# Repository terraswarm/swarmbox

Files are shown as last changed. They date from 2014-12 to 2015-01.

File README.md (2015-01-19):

SwarmBox
========

Testbed for the swarm of things.

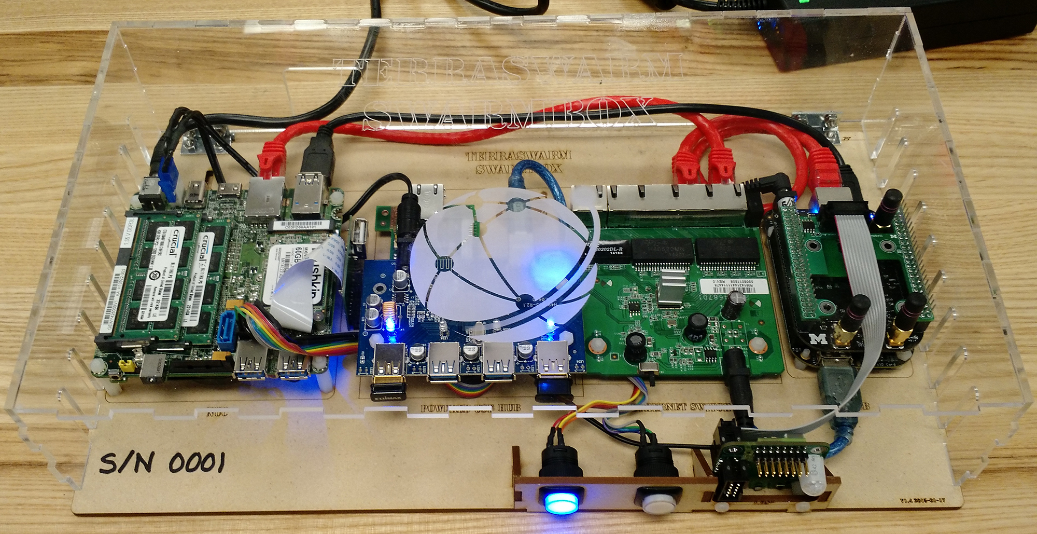
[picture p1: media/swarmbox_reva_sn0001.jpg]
Swarm Box RevA


Additional details documented in the [Terraswarm wiki](http://www.terraswarm.org/testbeds/wiki/Main/Hardware, "Terraswarm wiki, Hardware")

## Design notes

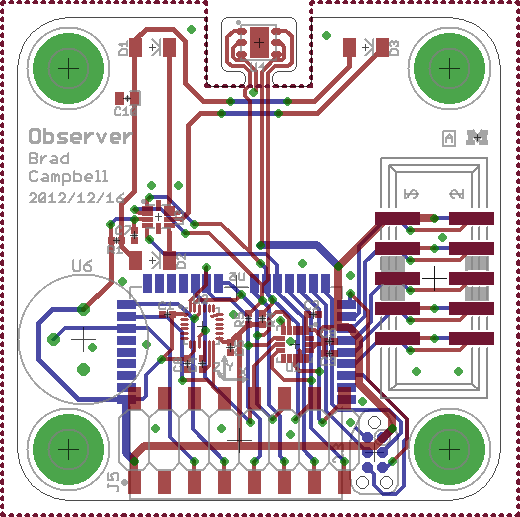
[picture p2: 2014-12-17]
hardware/observer/rev_a/observer_pcb.png

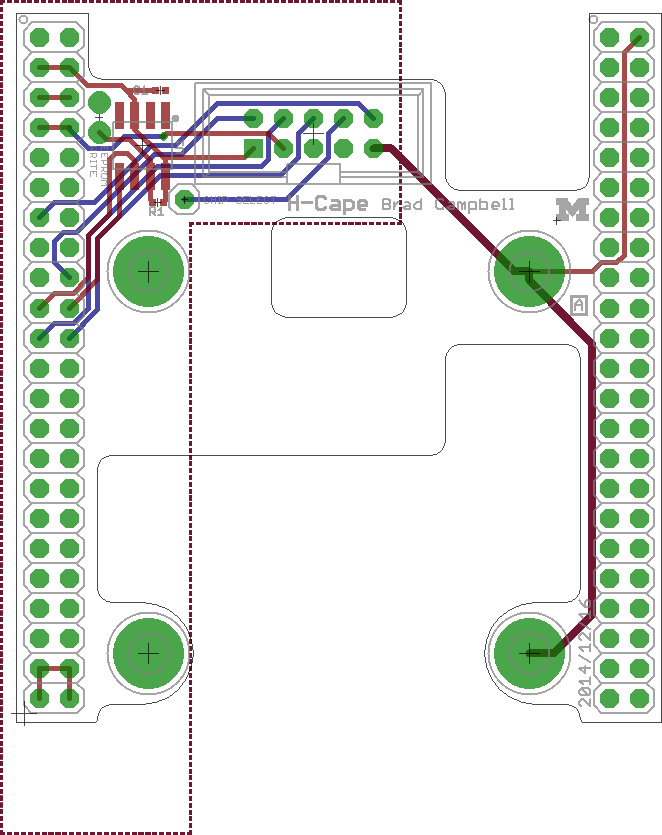
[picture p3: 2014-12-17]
hardware/ocape/rev_a/ocape_pcb.png

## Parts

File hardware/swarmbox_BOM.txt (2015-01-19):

Quantity   Component                 Model Number        Unit Cost        Link
--------   -----------------------   ----------------    ---------        ---------------------------------------------------------------
1          NUC (i5-4250U)            D54250WYB           $  352.99        http://www.newegg.com/Product/Product.aspx?Item=N82E16813121795
1          RAM (8GB)                 CT2CP51264BF160B    $   66.99        http://www.amazon.com/Crucial-4GBx2-DDR3-1600-CT2CP51264BF160B/dp/B005LDLVAO
1          SSD (80GB)                SSDMCEAW080A401     $   69.99        http://www.newegg.com/Product/Product.aspx?Item=N82E16820167196
1          PCIe Mini Adapter Cable   MPCIE-1XUSB-FLEX    $   27.60        http://www.amazon.com/PCI-E-Express-Riser-Speed-Cable/dp/B00JIV9AZS
1          i210 PCIe Card            E0X95AA             $   39.00        http://www.bhphotovideo.com/bnh/controller/home?sku=1024193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
1          Power Supply              FSP065-REB-R        $   25.99        http://www.newegg.com/Product/Product.aspx?Item=N82E16817104190

1          5 Port Ethernet Switch    GS105               $   30.19        http://www.amazon.com/NETGEAR-ProSafe-Gigabit-Ethernet-Desktop/dp/B0000BVYT3
1          Powered USB Hub           AH111               $   27.99        http://www.amazon.com/Anker¨-AH111-4-Port-Adapter-Chipset/dp/B005QWY3PU
1          BLE Dongle                MUA-BA3             $   11.99        http://www.amazon.com/Medialink-USB-Bluetooth-Adapter-Technology/dp/B004LNXO28
1          Wi-Fi Dongle              EW-7811Un           $    8.99        http://www.amazon.com/Edimax-EW-7811Un-150Mbps-Raspberry-Supports/dp/B003MTTJOY
1          USB Mini Cable            ?? (length?)
1          Ethernet Cat6 Cable       ?? (length?)
1          Ethernet Cat6 Cable       ?? (length?)

1 (??)     Power/Buttons Cable ??

1          Beaglebone Black Rev C    BB-BBLK-C           $   50.31        http://www.newark.com/element14/bbone-black-4g/beaglebone-black-rev-c-cortex/dp/52X5548

1          GAP Radio Board           GAP_C               $   75.00        https://github.com/lab11/beaglebone-cc2520/tree/master/hardware/eagle/bbb-cc2520/rev_c
1          H-Cape                    H-Cape_A            $   20.00
1          Observer                  Observer_C          $   80.00

1          Blue Push Button          1477                $    1.95        http://www.adafruit.com/products/1477
1          White Push Button         1479                $    1.95        http://www.adafruit.com/products/1479

??         3/4" (?) Standoffs
??         1/4" (?) Standoff
2          Hinges

1          Case                                                           https://github.com/terraswarm/swarmbox/tree/master/hardware/case

## OPTIONAL

1          PCIe Wi-Fi/BLE Card       INT-7260BR          $   23.99        http://www.superbiiz.com/detail.php?p=INT-7260BR
2          Wi-Fi Antenna             ??

## OLD, to be deleted

#5V 2A PSU for Beagle Bone        Received        $8        http://www.adafruit.com/products/276        2A needed for Wifi dongle+BBB
#uSD card        19x Received        $15.99        http://www.amazon.com/SanDisk-Memory-Adapter--SDSDQUAN-032G-G4A-Version/dp/B00M55C0NS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        BeagleBone Linux Image

usb 2.0 hub        20x received        $6.99        http://www.amazon.com/Sabrent-4-Port-Individual-Switches-HB-UMLS/dp/B00BWF5U0M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        For BBB wireless dongles etc.                                        http://www.amazon.com/Sabrent-4-Port-Individual-Switches-HB-UM43/dp/B00JX1ZS5O

standoffs        5 sets revceived        10.89        http://www.amazon.com/gp/product/B00LGB2N1Q/ref=ox_sc_act_image_2?ie=UTF8&psc=1&smid=A2W8GBH769XLCV        Holders for the NUC and Beaglebone
Z-Wave USB Stick        20x received        $39        http://www.amazon.com/Aeon-Labs-DSA02203-ZWUS-Z-Wave-Z-Stick/dp/B003MWQ30E        Aeon Labs
ethernet station cable x 2                $6                to go to local gig switch
Radio Cape                $75.00        Custom        Estimate (high)
Power Button                $1.95        http://www.adafruit.com/products/1477
Reset Buton/HDD Indicator                $1.95        http://www.adafruit.com/products/1479
WiFi Antennas x2                $9.90        http://www.mouser.com/Search/ProductDetail.aspx?R=47950-0001virtualkey53850000virtualkey538-47950-0001
Internal Power Header Conductors x2                $0.84        http://www.mouser.com/Search/ProductDetail.aspx?R=39-00-0039virtualkey53810000virtualkey538-39-00-0039
Internal Power Header                $0.61        http://www.mouser.com/Search/ProductDetail.aspx?R=39-02-7028virtualkey53850000virtualkey538-39-02-7028

Total Per Unit                $733.80

Accessories (couple per group)                Unit Cost
HDMI cable        8x received        $7        http://www.amazon.com/AmazonBasics-High-Speed-HDMI-Micro-Cable/dp/B0096LZ5QI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
usb a mini b cable        8x Received        $5.09        http://www.amazon.com/AmazonBasics-USB-Male-Mini-Cable/dp/B00E9IF9RI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
3M Velcro        1 set received        $75        http://www.amazon.com/CommandTM-Adhesive-Interlocking-Fasteners-ADHESIVE/dp/B0032K0EIS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        30 Pack
hdmi monitor                99        http://www.newegg.com/Product/Product.aspx?Item=N82E16824236115
usb keyboard        20x received        15.99        http://www.newegg.com/Product/Product.aspx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                with mouse and speakers
Beagle Bone Debug Console cable        10 x Revceived        19.95        http://www.amazon.com/3-3V-Debug-Cable-BeagleBone-Black/dp/B00FA7LD0Y
Esplora (sensors/actuator mix        CNMAT will bring loaners        49.99        http://www.radioshack.com/arduino-esplora-microcontroller-board/2760261.html#.VIKtJd6kZs8                light/temp/slider/rgb led/buttons/sound via usb
Optional hdmi to VGA                15.99        http://www.amazon.com/Cable-Matters-Active-Female-Adapter/dp/B00879EZJI/
Total Accessories                $186

For Workshop Experiments/Config
AVB switch        3 loaners received by Meyer Sound for workshop        295        http://www.bhphotovideo.com/bnh/controller/home?sku=1071378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        6-ports
24-bit qos switch        2x Received        169.99        http://www.amazon.com/TP-LINK-TL-SG2424-Snooping-Web-based-Management/dp/B009LEJL5Q                supports 12nucs and 12 bbb
PTZ camera with 2 way audio        3x received        63.99        http://www.amazon.com/Foscam-FI8910W-Network-Camera-Two-Way/dp/B006ZP8UOW        actuation and streaming source controllable with ZoneMinder for remote config guidance

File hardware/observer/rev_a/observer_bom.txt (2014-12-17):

# Bill of Materials
# Converted from observer_bom.xlsx
# Generated by bom_to_text.py

Qty  Value                         Device                        Package           Parts                   Description                                                 DIGIKEY
1    10nF                          CAPACITOR                     0402_CAP          C1                      0402 Capacitor                                              490-1312-1-ND
6    0.1uF                         CAPACITOR                     0402_CAP          C2, C3, C4, C5, C7, C8  0402 Capacitor                                              490-1318-1-ND
1    10uF                          CAPACITOR                     0402_CAP          C9                      0402 Capacitor                                              445-8919-1-ND
1    22uF                          CAP_POL0603                   CAP0603           C10                                                                                 511-1493-1-ND
3    SFH4056                       SFH4056                       SFH4056           D1, D2, D3              LED IR EMITTER 850NM                                        475-3042-1-ND
2    CON_HEADER_2X05-SMD+SHROUDED  CON_HEADER_2X05-SMD+SHROUDED  PINSHRD_SMT_2X05  J1, J2                  2x05 pin header                                             S9185-ND
1    PINHD-2X8/SMD                 PINHD-2X8/SMD                 2X8/SMD           J5                                                                                  609-3486-1-ND
1    30                            RESISTOR0402_RES              0402_RES          R1                      Resistor                                                    RHM30CECT-ND
2    10k                           RESISTOR0402_RES              0402_RES          R4, R5                  Resistor                                                    RHM10.0KCDCT-ND
1    LPS331AP                      LPS331AP                      HCLGA-16/3MM      U1                      IC PRESSURE SENSOR PIEZO 16HCLGA                            497-12927-1-ND
1    MPU-9250                      MPU-9250                      QFN-24/3MM        U2                      GYRO/ACCEL/COMPASS/9-AXIS                                   1428-1019-1-ND
1    SI1147                        SI1147                        QFN-10/2MM        U3                      SENSOR DGTL UV INDEX 10QFN                                  336-2624-1-ND
1    SI7021                        SI7021                        DFN-6/3MM         U4                      IC TEMP SENSOR RH 2% DFN                                    336-2542-1-ND
1    ATUM                          ATUM                          ATUM              U5                      Atum sensorboard prototyping module.                        
1    AMN41121                      AMN41121                      AMN2              U6                      Passive infrared human detection sensor with built-in amp.  255-2651-ND

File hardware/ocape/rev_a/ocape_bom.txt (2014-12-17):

# Bill of Materials
# Converted from ocape_bom.xlsx
# Generated by bom_to_text.py

Qty  Value                           Device                          Package                  Parts  Description                                                         DIGIKEY
1    100nF                           C-EUC0402                       C0402                    C1     CAPACITOR, European symbol                                          490-1318-1-ND
1    CON_HEADER_2X05-PTH+SHROUDED_A  CON_HEADER_2X05-PTH+SHROUDED_A  PINSHRD_PTH_2X05         J1     2x05 pin header                                                     ED1543-ND
1    JUMPER-PTH-2-NO                 JUMPER-PTH-2-NO                 PTH-JUMPER-2-NO_NO_SILK  J2                                                                         
1                                    PINHD-1X1                       1X01                     J3     PIN HEADER                                                          
1    BBB_HEADERS                     BBB_HEADERS                     BBB_HEADERS              P9/P8  Pin Header                                                          
1    10k 1%                          R-US_R0402                      R0402                    R1     RESISTOR, American symbol                                           RHM10.0KCDCT-ND
1    CAT24C256WI-GT3                 CAT24C256WI-GT3                 CAT24C256WI-GT3          U1     256kb Serial CMOS EEPROM, organized as 32,768 words of 8 bits each  CAT24C256WI-GT3OSCT-ND

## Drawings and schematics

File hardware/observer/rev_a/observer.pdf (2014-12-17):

Pressure Sensor | 9-DOF Accelerometer

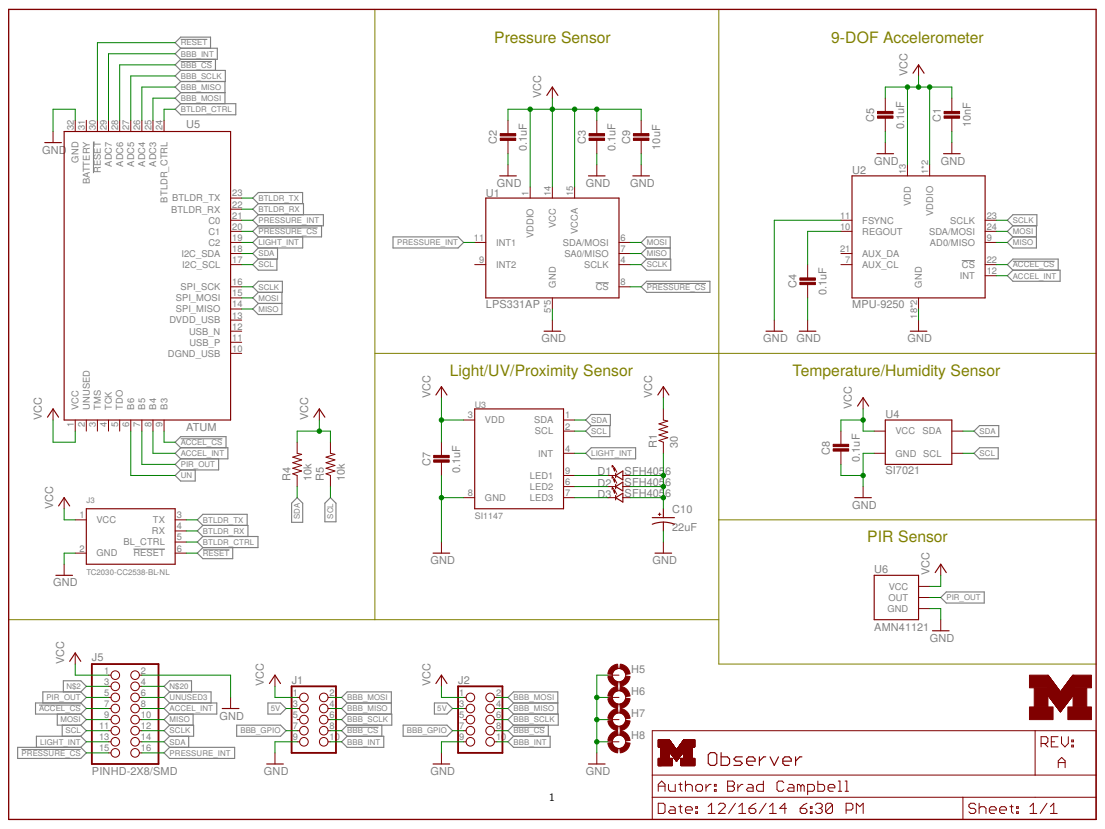
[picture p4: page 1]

Top and Bottom Layers 2 | 21 | 12

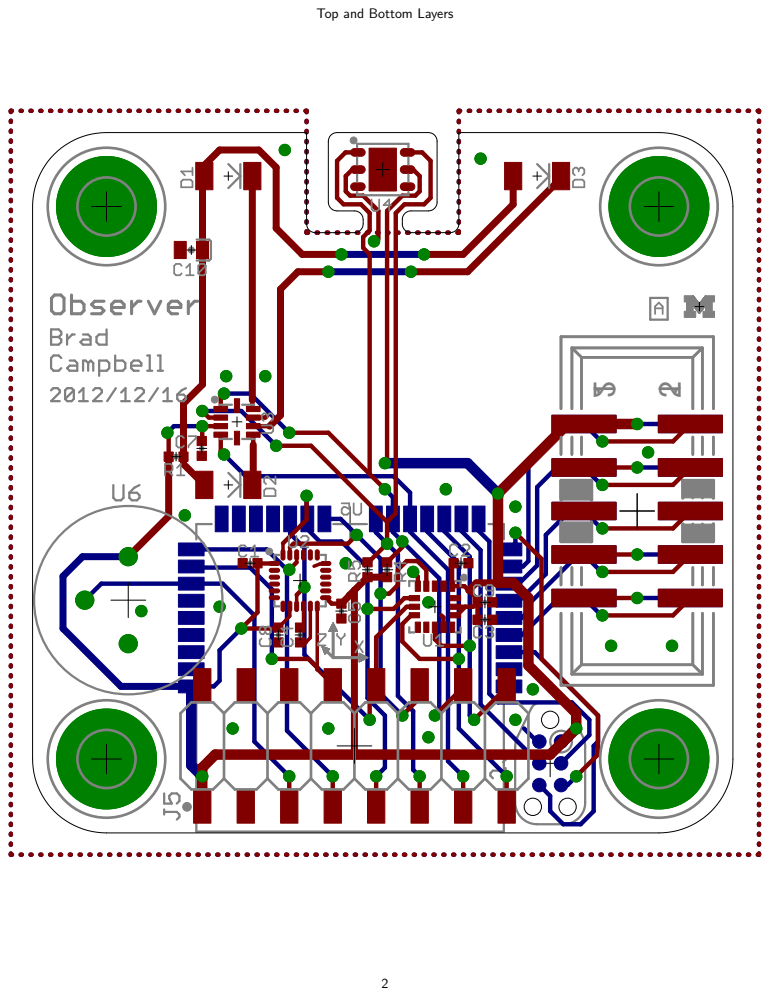
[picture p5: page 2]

Top Layer 3 | 1 | 2

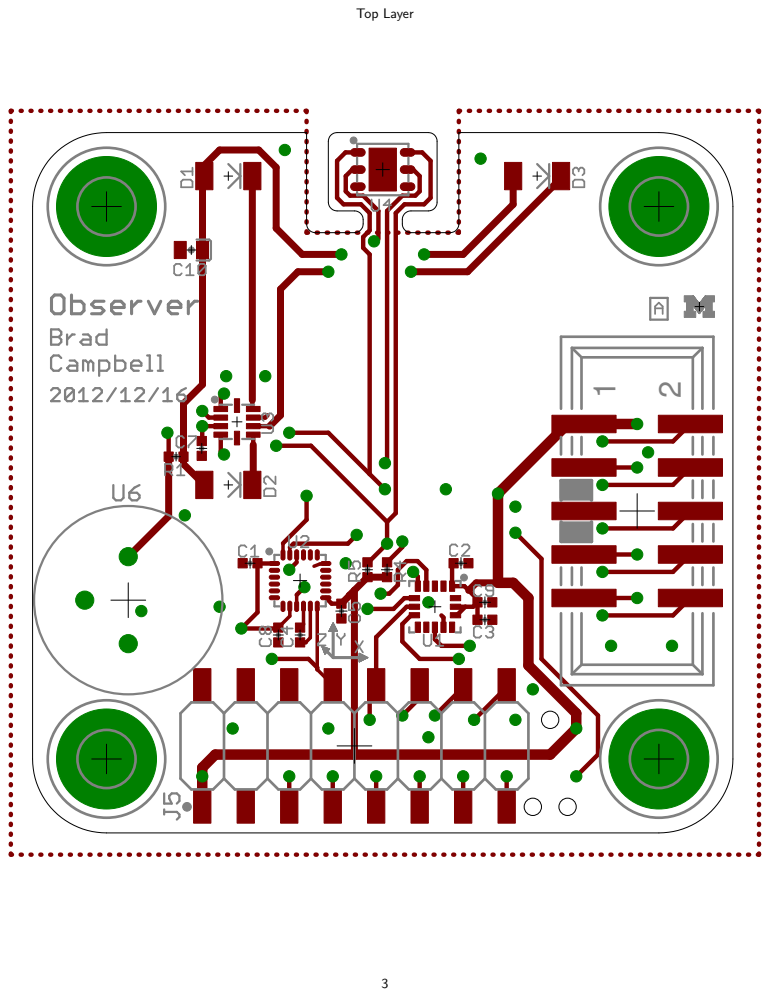
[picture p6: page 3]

# Bottom Layer 4 1 2

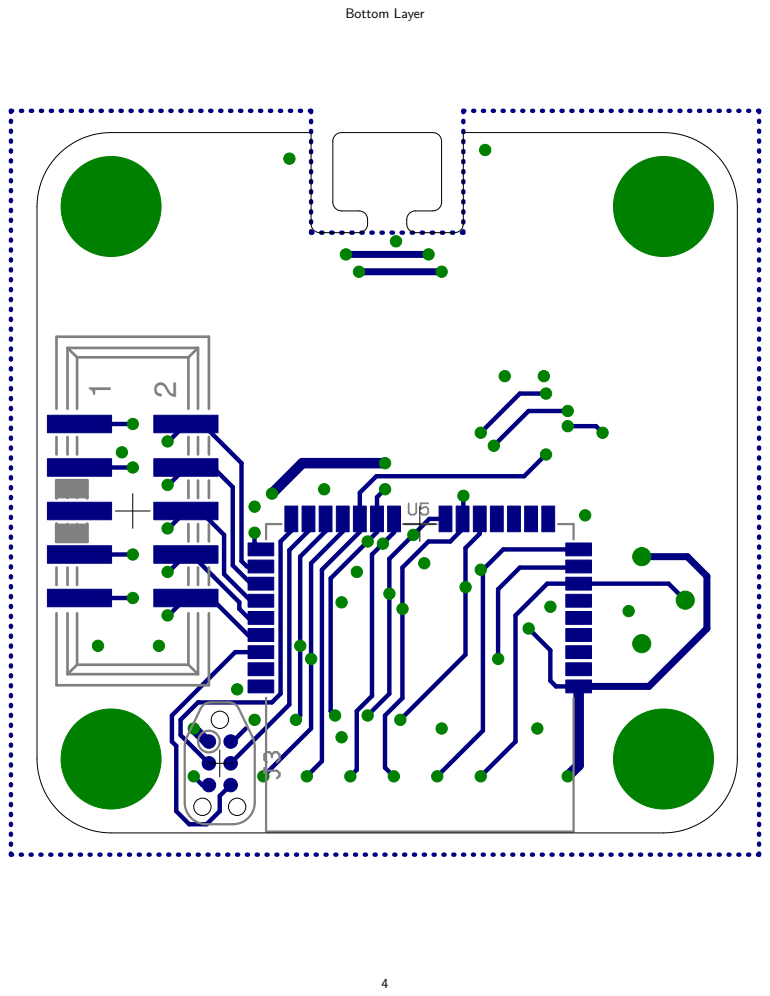
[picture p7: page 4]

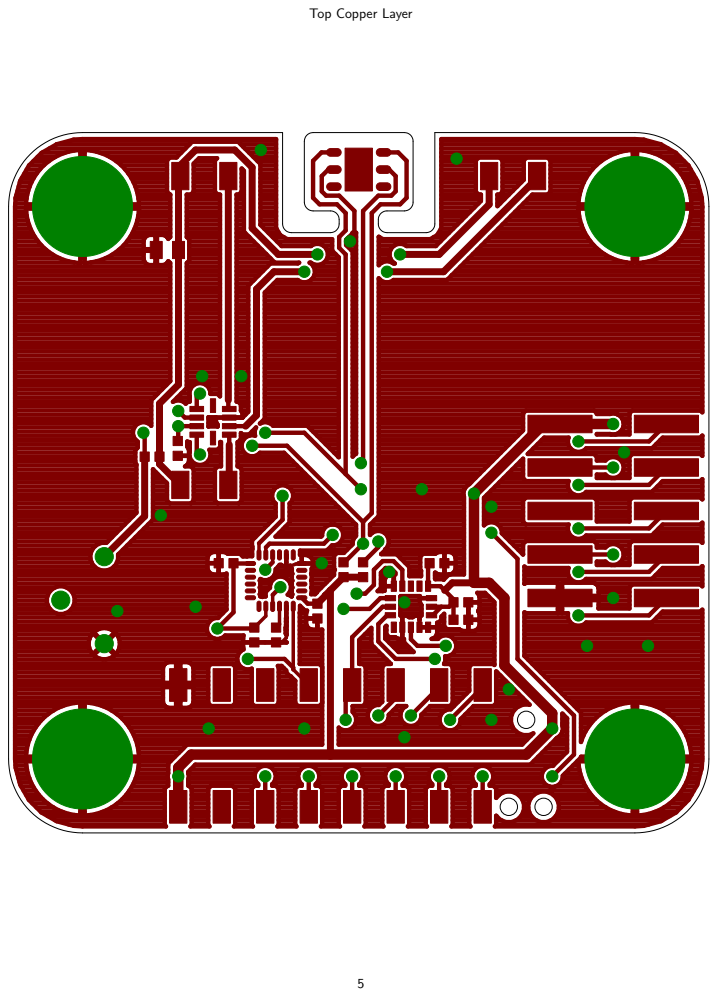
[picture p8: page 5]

Top Copper Layer

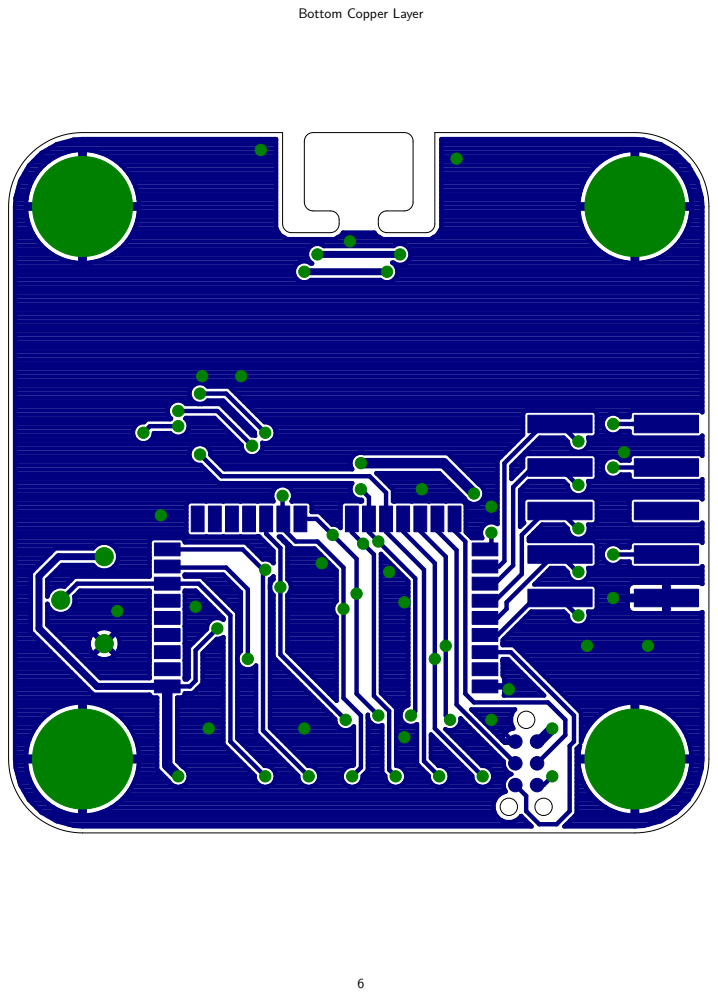
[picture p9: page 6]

Bottom Copper Layer

Top Paste Layer with Silkscreen 7 | 1 | 2

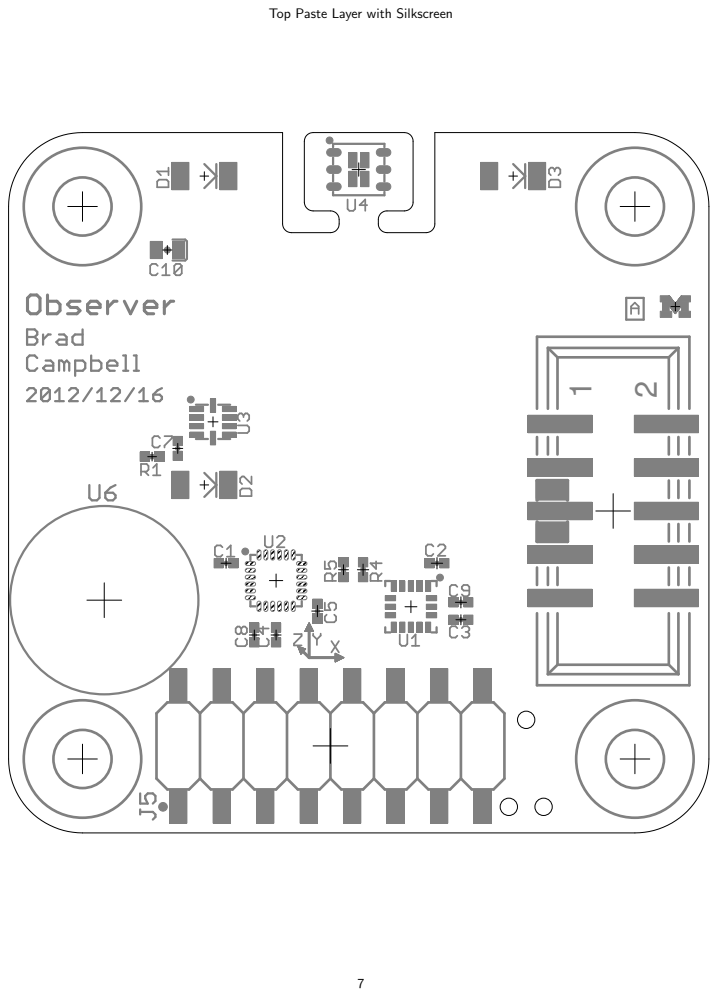
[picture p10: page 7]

# Bottom Paste Layer with Silkscreen 8 1 2

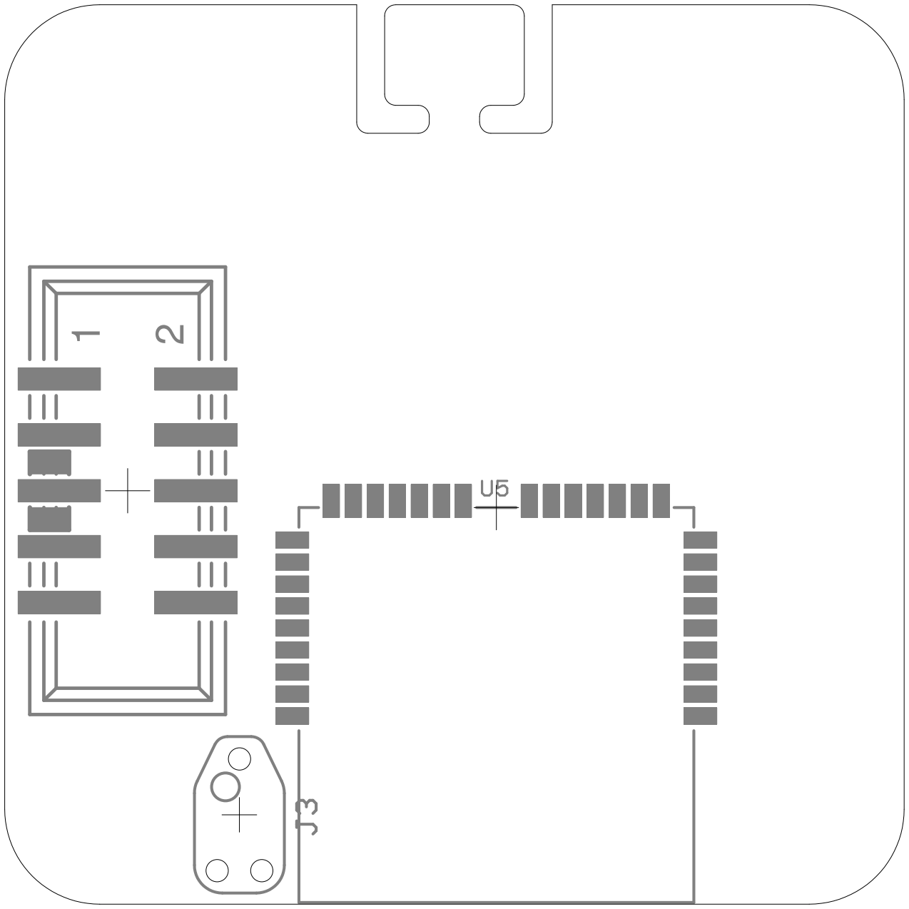
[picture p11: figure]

Top and Bottom Layers 1:1 Scale 9 | 21 | 12

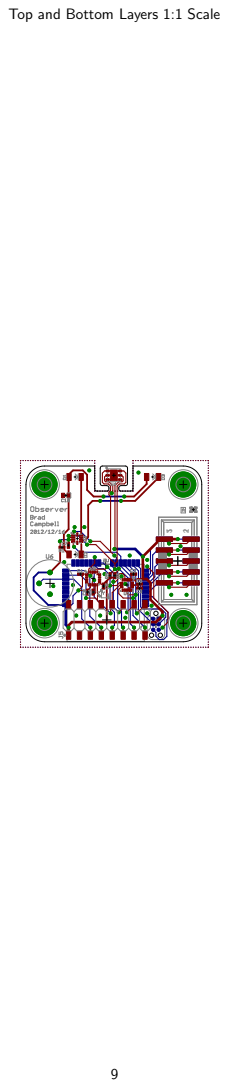
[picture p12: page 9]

Top Layer 1:1 Scale

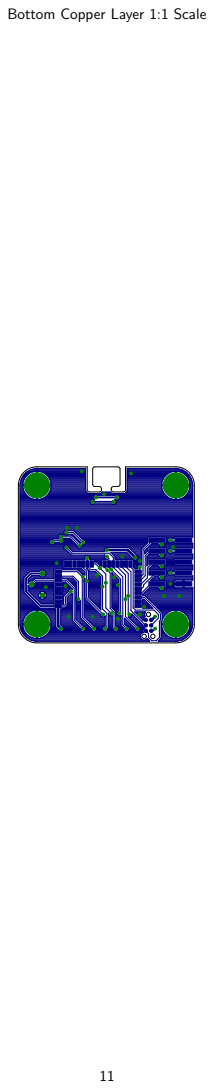
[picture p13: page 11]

Bottom Copper Layer 1:1 Scale

### Sheet1

Qty Value | Device
1 10nF | CAPACITOR
6 0.1uF | CAPACITOR
1 10uF | CAPACITOR
1 22uF | CAP_POL0603
3 SFH4056 | SFH4056
2 CON_HEADER_2X05-SMD+SHROUDED CON_HEADER_2X05-SMD+SHROUDED
1 PINHD-2X8/SMD | PINHD-2X8/SMD
1 30 | RESISTOR0402_RES
2 10k | RESISTOR0402_RES
1 LPS331AP | LPS331AP
1 MPU-9250 | MPU-9250
1 SI1147 | SI1147
1 SI7021 | SI7021
1 ATUM | ATUM
1 AMN41121 | AMN41121

### Sheet1

Package | Parts | Description
0402_CAP | C1 | 0402 Capacitor
0402_CAP | C2, C3, C4, C5, C7, C8 0402 Capacitor
0402_CAP | C9 | 0402 Capacitor
CAP0603 | C10
SFH4056 | D1, D2, D3 | LED IR EMITTER 850NM
PINSHRD_SMT_2X05 J1, J2 | 2x05 pin header
2X8/SMD | J5
0402_RES | R1 | Resistor
0402_RES | R4, R5 | Resistor
HCLGA-16/3MM | U1 | IC PRESSURE SENSOR PIEZO 16HCLGA
QFN-24/3MM | U2 | GYRO/ACCEL/COMPASS/9-AXIS
QFN-10/2MM | U3 | SENSOR DGTL UV INDEX 10QFN
DFN-6/3MM | U4 | IC TEMP SENSOR RH 2% DFN
ATUM | U5 | Atum sensorboard prototyping module.
AMN2 | U6 | Passive infrared human detection sensor with built-in amp.

### Sheet1

DIGIKEY
490-1312-1-ND
490-1318-1-ND
445-8919-1-ND
511-1493-1-ND
475-3042-1-ND
S9185-ND
609-3486-1-ND
RHM30CECT-ND
RHM10.0KCDCT-ND
497-12927-1-ND
1428-1019-1-ND
336-2624-1-ND
336-2542-1-ND

255-2651-ND

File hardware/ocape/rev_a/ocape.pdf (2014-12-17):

# BeagleBone Black Header

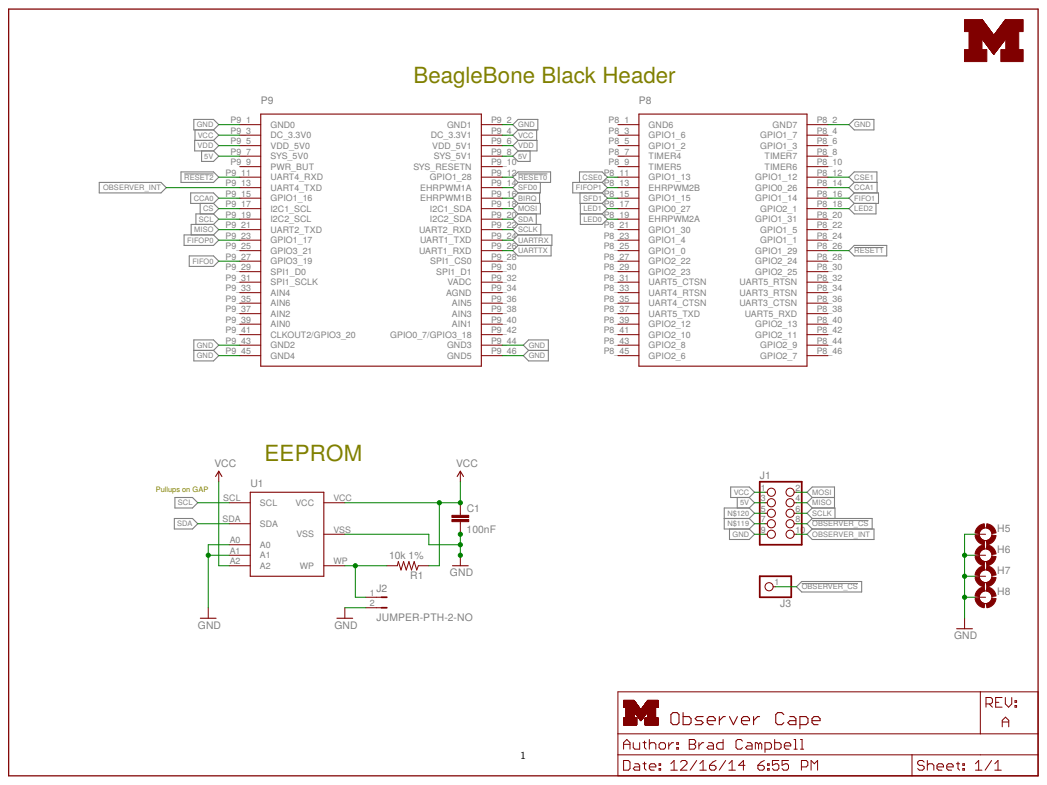
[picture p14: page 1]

Pullups on GAP VCC

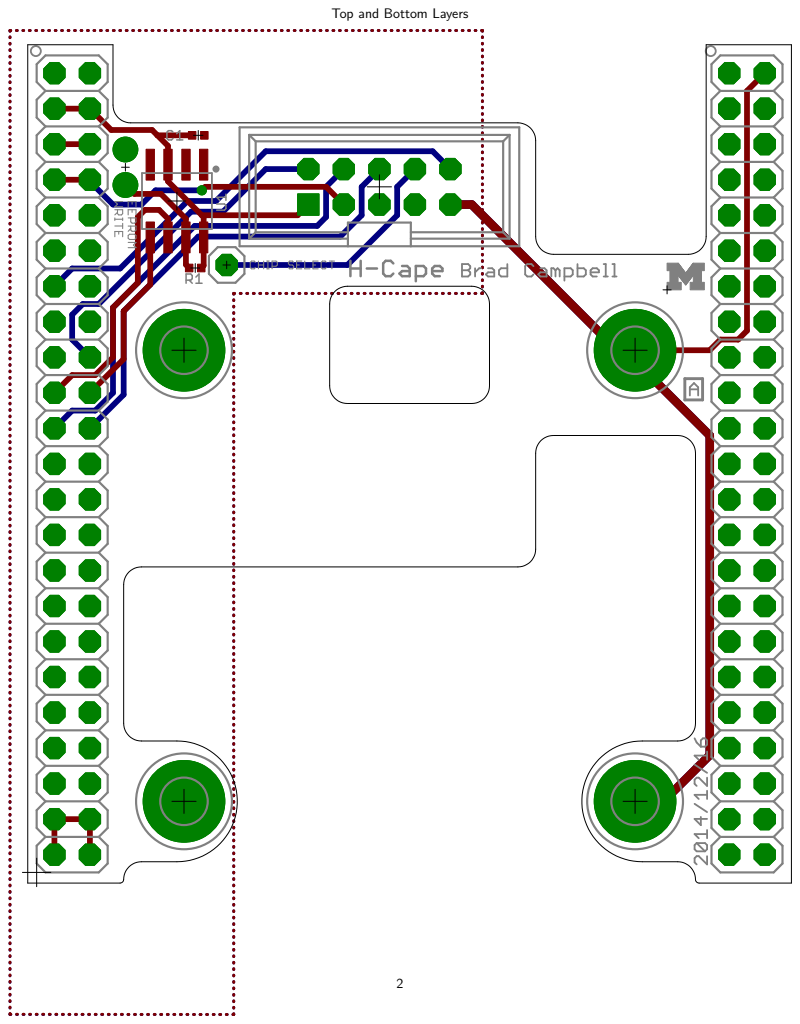
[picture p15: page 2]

Top and Bottom Layers

Top Layer

Bottom Layer


Top Copper Layer


Bottom Copper Layer


Top Paste Layer with Silkscreen


Bottom Paste Layer with Silkscreen


Top and Bottom Layers 1:1 Scale


Top Layer 1:1 Scale


Bottom Copper Layer 1:1 Scale

## Sheet1

Qty Value | Device
1 100nF | C-EUC0402

### 1 CON_HEADER_2X05-PTH+SHROUDED_A CON_HEADER_2X05-PTH+SHROUDED_A

1 JUMPER-PTH-2-NO | JUMPER-PTH-2-NO
1 | PINHD-1X1
1 BBB_HEADERS | BBB_HEADERS
1 10k 1% | R-US_R0402
1 CAT24C256WI-GT3 | CAT24C256WI-GT3

## Sheet1

Package | Parts
C0402 | C1
PINSHRD_PTH_2X05 | J1

### PTH-JUMPER-2-NO_NO_SILK J2

1X01 | J3
BBB_HEADERS | P9/P8
R0402 | R1
CAT24C256WI-GT3 | U1

## Sheet1

Description | DIGIKEY
CAPACITOR, European symbol | 490-1318-1-ND
2x05 pin header | ED1543-ND

### PIN HEADER Pin Header

RESISTOR, American symbol | RHM10.0KCDCT-ND

### 256kb Serial CMOS EEPROM, organized as 32,768 words of 8 bits each CAT24C256WI-GT3OSCT-ND

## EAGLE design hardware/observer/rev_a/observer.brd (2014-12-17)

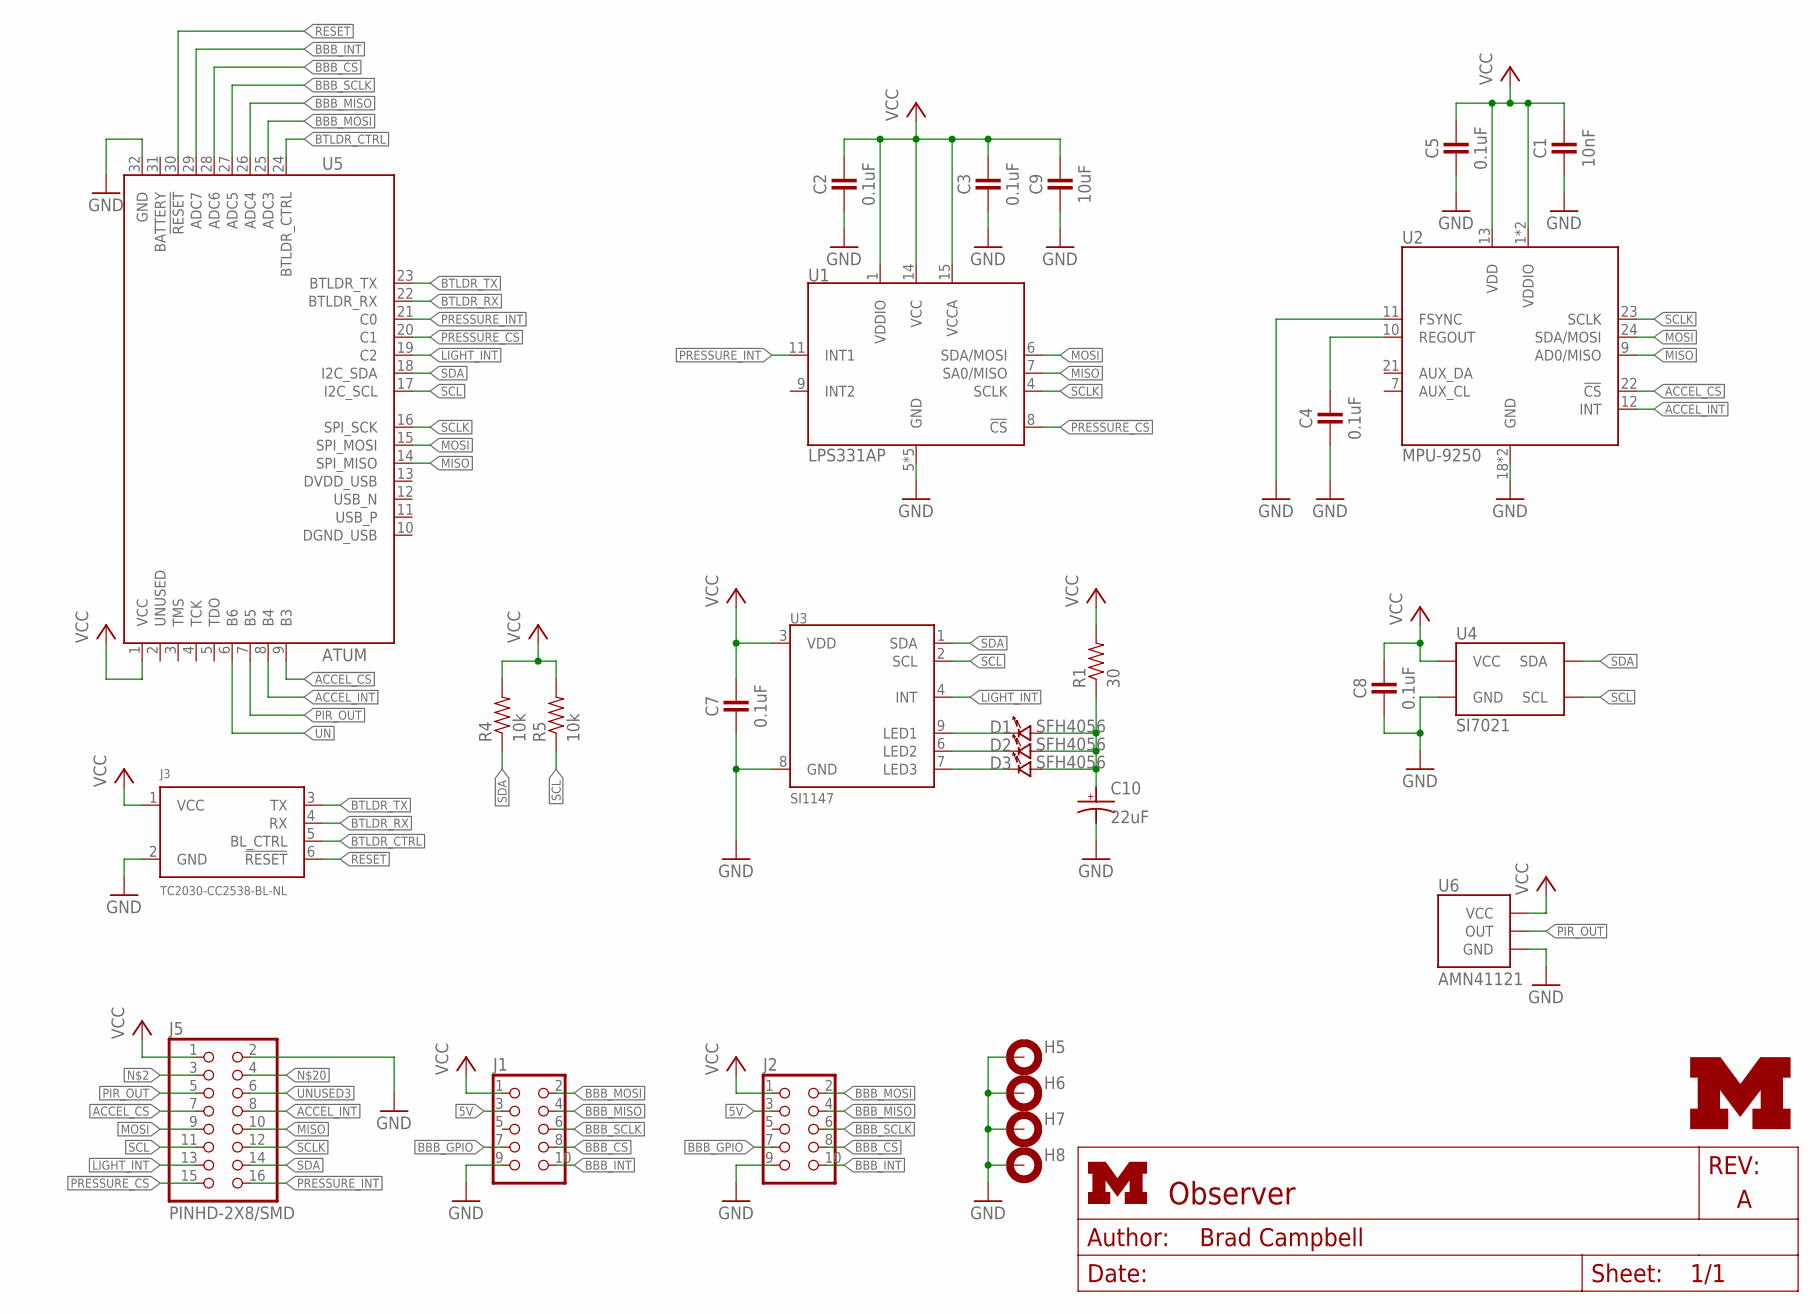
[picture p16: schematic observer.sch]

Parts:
C1: 10nF; 0402_CAP; DIGIKEY 490-1312-1-ND
C2, C3, C4, C5, C7, C8: 0.1uF; 0402_CAP; DIGIKEY 490-1318-1-ND
C9: 10uF; 0402_CAP; DIGIKEY 445-8919-1-ND
C10: 22uF; CAP0603; DIGIKEY 511-1493-1-ND
D1, D2, D3: SFH4056
H5, H6, H7, H8: MOUNT-PAD-ROUND3.2; 3,2-PAD
J1, J2: CON_HEADER_2X05-SMD+SHROUDED; PINSHRD_SMT_2X05; DIGIKEY S9185-ND
J3: TC2030-CC2538-BL-NL; TC2030-IDC-NL
J5: PINHD-2X8/SMD; 2X8/SMD
LOGO1: UMICH_SOLID_TINY; UMICH_SOLID_50MIL
R1: 30; 0402_RES; DIGIKEY RHM30CECT-ND
R4, R5: 10k; 0402_RES; DIGIKEY RHM10.0KCDCT-ND
U1: LPS331AP; HCLGA-16/3MM
U2: MPU-9250; QFN-24/3MM
U3: SI1147; QFN-10/2MM
U4: SI7021; DFN-6/3MM
U5: ATUM
U6: AMN41121; AMN2

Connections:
5V: J1.3, J2.3
!ACCEL_CS: J5.7, U2.22 (!CS), U5.9 (B3)
!BBB_CS: J1.8, J2.8, U5.28 (ADC6)
!PRESSURE_CS: J5.15, U1.8 (!CS), U5.20 (C1)
!RESET: J3.6 (!RESET), U5.30 (!RESET)
ACCEL_INT: J5.8, U2.12 (INT), U5.8 (B4)
BBB_GPIO: J1.7, J2.7
BBB_INT: J1.10, J2.10, U5.29 (ADC7)
BBB_MISO: J1.4, J2.4, U5.26 (ADC4)
BBB_MOSI: J1.2, J2.2, U5.25 (ADC3)
BBB_SCLK: J1.6, J2.6, U5.27 (ADC5)
BTLDR_CTRL: J3.5 (BL_CTRL), U5.24 (BTLDR_CTRL)
BTLDR_RX: J3.4 (RX), U5.22 (BTLDR_RX)
BTLDR_TX: J3.3 (TX), U5.23 (BTLDR_TX)
GND: C1.2, C2.2, C3.2, C4.2, C5.2, C7.2, C8.2, C9.2, C10.NEG (ANODE), H5.B3,2, H6.B3,2, H7.B3,2, H8.B3,2, J1.9, J2.9, J3.2 (GND), J5.2, U1.5 (GND), U1.10 (GND), U1.12 (GND), U1.13 (GND), U1.16 (GND), U2.11 (FSYNC), U2.18 (GND), U2.20 (GND), U3.8 (GND), U4.2 (GND), U5.32 (GND), U6.GND
LIGHT_INT: J5.13, U3.4 (INT), U5.19 (C2)
MISO: J5.10, U1.7 (SA0/MISO), U2.9 (AD0/MISO), U5.14 (SPI_MISO)
MOSI: J5.9, U1.6 (SDA/MOSI), U2.24 (SDA/MOSI), U5.15 (SPI_MOSI)
unnamed: C4.1, U2.10 (REGOUT)
unnamed: D1.CATHODE, U3.9 (LED1)
unnamed: D2.CATHODE, U3.6 (LED2)
unnamed: D3.CATHODE, U3.7 (LED3)
unnamed: C10.POS (CATHODE), D1.ANODE, D2.ANODE, D3.ANODE, R1.1
PIR_OUT: J5.5, U5.7 (B5), U6.OUT
PRESSURE_INT: J5.16, U1.11 (INT1), U5.21 (C0)
SCL: J5.11, R5.1, U3.2 (SCL), U4.6 (SCL), U5.17 (I2C_SCL)
SCLK: J5.12, U1.4 (SCLK), U2.23 (SCLK), U5.16 (SPI_SCK)
SDA: J5.14, R4.1, U3.1 (SDA), U4.1 (SDA), U5.18 (I2C_SDA)
UN: U5.6 (B6)
UNUSED3: J5.6
VCC: C1.1, C2.1, C3.1, C5.1, C7.1, C8.1, C9.1, J1.1, J2.1, J3.1 (VCC), J5.1, R1.2, R4.2, R5.2, U1.1 (VDDIO), U1.14 (VCC), U1.15 (VCCA), U2.1 (VDDIO), U2.8 (VDDIO), U2.13 (VDD), U3.3 (VDD), U4.5 (VCC), U5.1 (VCC), U6.VCC

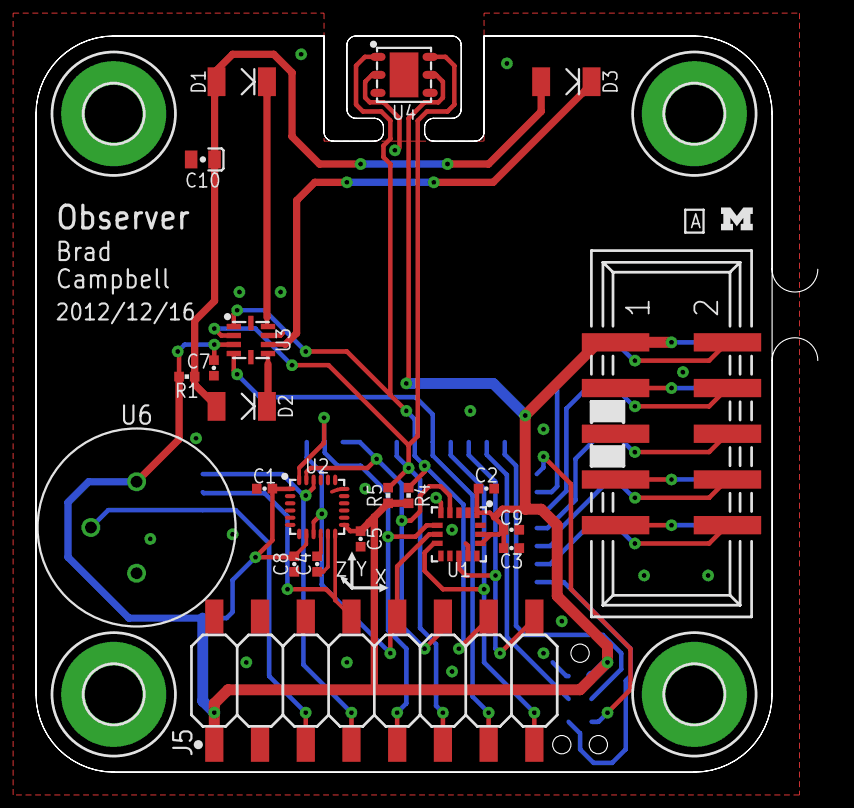
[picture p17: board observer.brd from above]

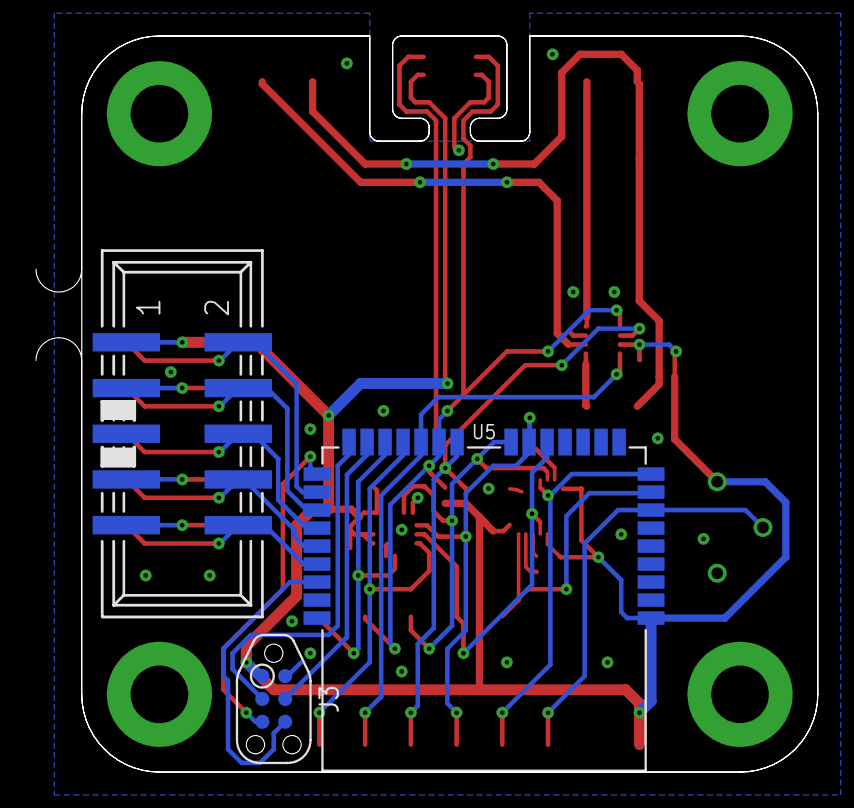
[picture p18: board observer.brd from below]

Board: 2 copper layers, 43.4 x 40.9 mm, 30 parts (3 on the bottom side), 29 nets.

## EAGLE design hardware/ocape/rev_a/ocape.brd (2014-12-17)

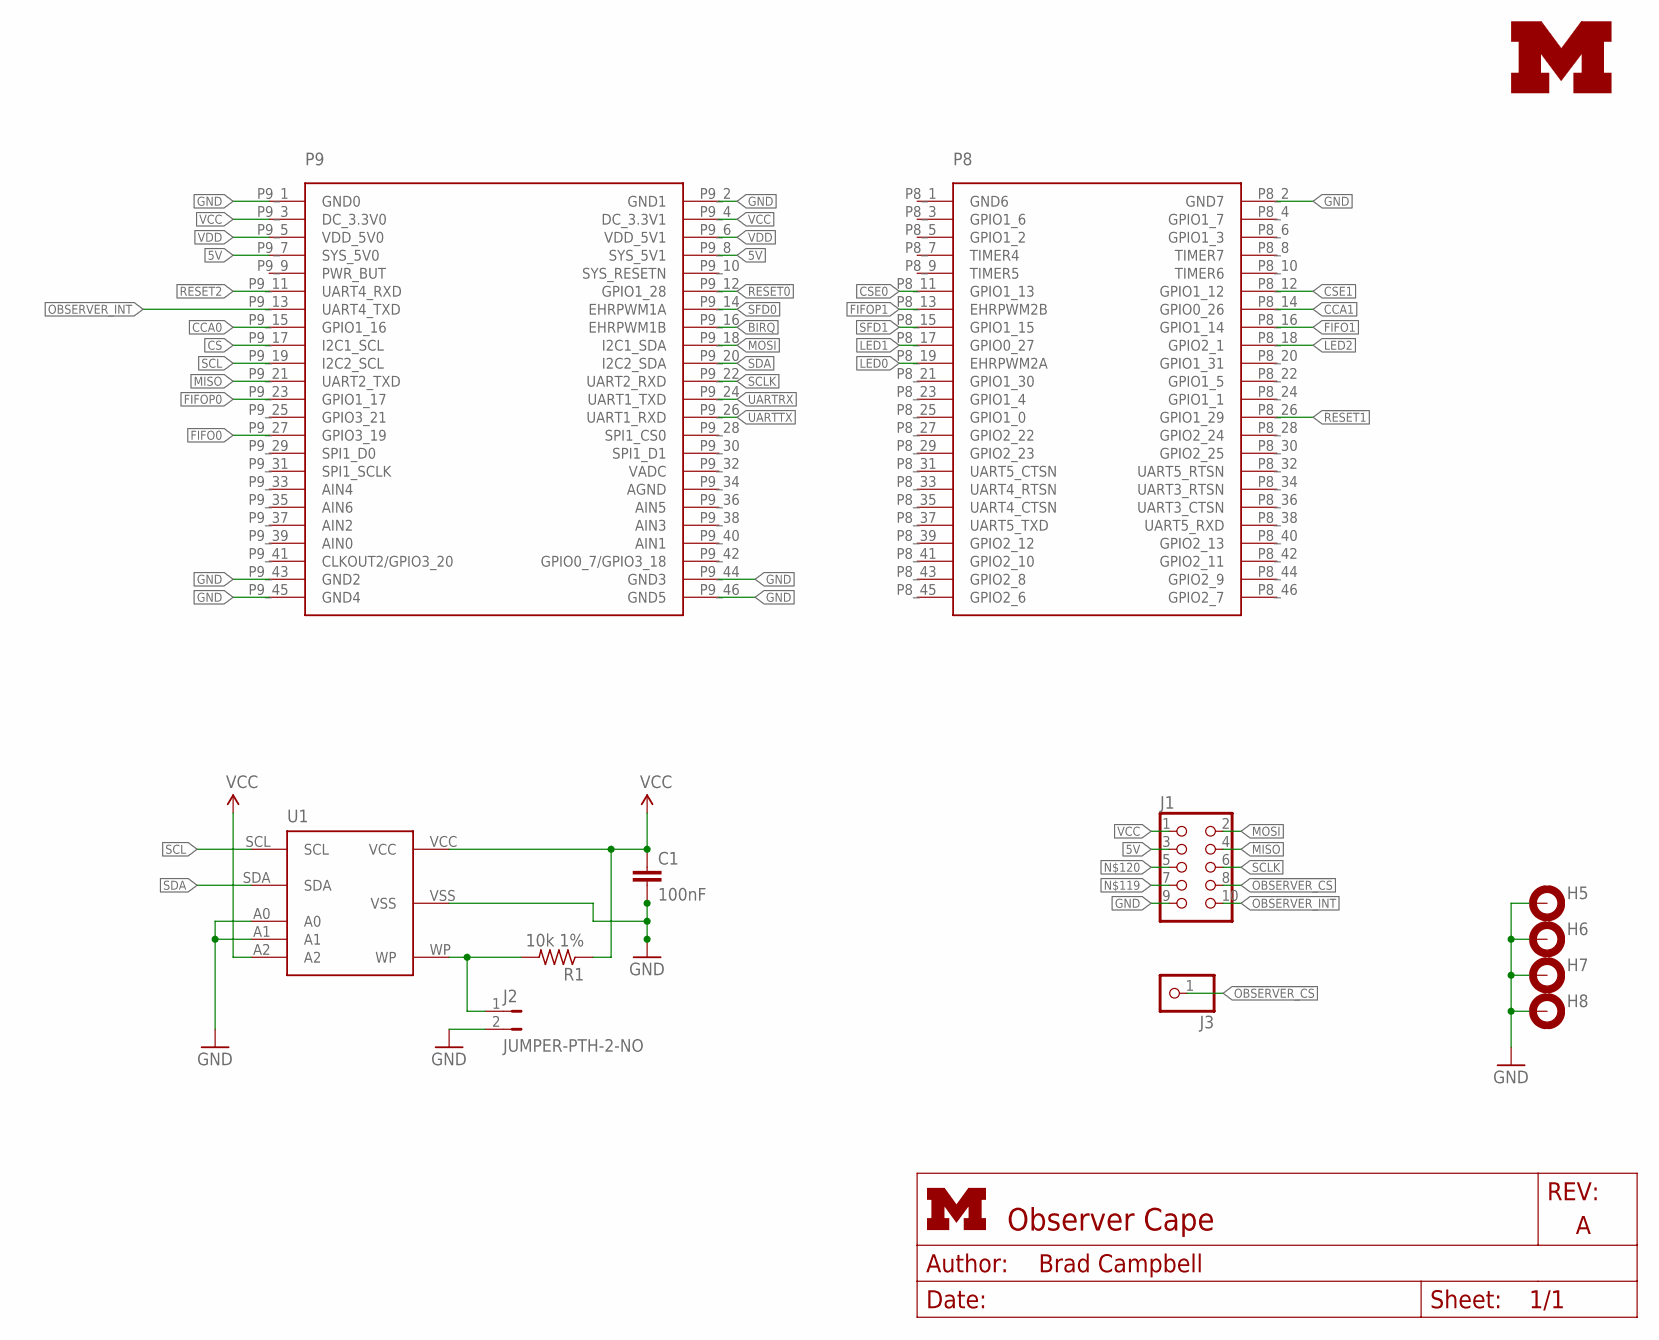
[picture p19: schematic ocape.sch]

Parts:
C1: 100nF; C0402; DIGIKEY 490-1318-1-ND
H5, H6, H7, H8: MOUNT-PAD-ROUND3.2; 3,2-PAD
J1: CON_HEADER_2X05-PTH+SHROUDED_A; PINSHRD_PTH_2X05
J2: JUMPER-PTH-2-NO; PTH-JUMPER-2-NO_NO_SILK
J3: PINHD-1X1; 1X01
LOGO1: UMICH_SOLID_SMALL; UMICH_SOLID_75MIL
P9/P8: BBB_HEADERS
R1: 10k 1%; R0402; DIGIKEY RHM1.00MCDCT-ND
U1: CAT24C256WI-GT3

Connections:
5V: J1.3, P9/P8.P9_7 (SYS_5V0), P9/P8.P9_8 (SYS_5V1)
!OBSERVER_CS: J1.8, J3.1
!RESET0: P9/P8.P9_12 (GPIO1_28)
!RESET1: P9/P8.P8_26 (GPIO1_29)
!RESET2: P9/P8.P9_11 (UART4_RXD)
BIRQ: P9/P8.P9_16 (EHRPWM1B)
CCA0: P9/P8.P9_15 (GPIO1_16)
CCA1: P9/P8.P8_14 (GPIO0_26)
CS: P9/P8.P9_17 (I2C1_SCL)
CSE0: P9/P8.P8_11 (GPIO1_13)
CSE1: P9/P8.P8_12 (GPIO1_12)
FIFO0: P9/P8.P9_27 (GPIO3_19)
FIFO1: P9/P8.P8_16 (GPIO1_14)
FIFOP0: P9/P8.P9_23 (GPIO1_17)
FIFOP1: P9/P8.P8_13 (EHRPWM2B)
GND: C1.2, H5.B3,2, H6.B3,2, H7.B3,2, H8.B3,2, J1.9, J2.2, P9/P8.P8_2 (GND7), P9/P8.P9_1 (GND0), P9/P8.P9_2 (GND1), P9/P8.P9_43 (GND2), P9/P8.P9_44 (GND3), P9/P8.P9_45 (GND4), P9/P8.P9_46 (GND5), U1.A0, U1.A1, U1.VSS
LED0: P9/P8.P8_19 (EHRPWM2A)
LED1: P9/P8.P8_17 (GPIO0_27)
LED2: P9/P8.P8_18 (GPIO2_1)
MISO: J1.4, P9/P8.P9_21 (UART2_TXD)
MOSI: J1.2, P9/P8.P9_18 (I2C1_SDA)
unnamed: J2.1, R1.2, U1.WP
OBSERVER_INT: J1.10, P9/P8.P9_13 (UART4_TXD)
SCL: P9/P8.P9_19 (I2C2_SCL), U1.SCL
SCLK: J1.6, P9/P8.P9_22 (UART2_RXD)
SDA: P9/P8.P9_20 (I2C2_SDA), U1.SDA
SFD0: P9/P8.P9_14 (EHRPWM1A)
SFD1: P9/P8.P8_15 (GPIO1_15)
UARTRX: P9/P8.P9_24 (UART1_TXD)
UARTTX: P9/P8.P9_26 (UART1_RXD)
VCC: C1.1, J1.1, P9/P8.P9_3 (DC_3.3V0), P9/P8.P9_4 (DC_3.3V1), R1.1, U1.A2, U1.VCC
VDD: P9/P8.P9_5 (VDD_5V0), P9/P8.P9_6 (VDD_5V1)

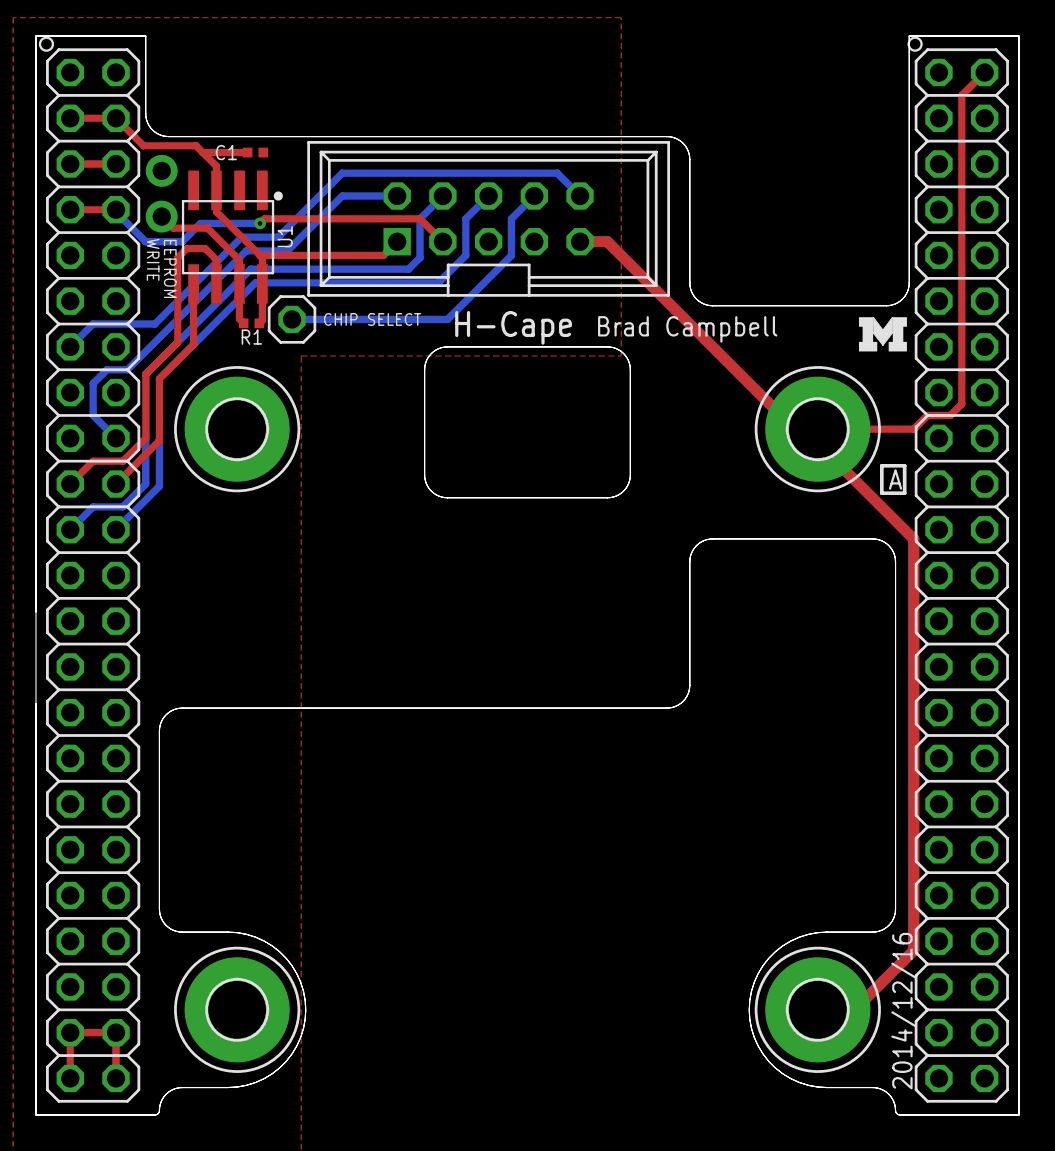
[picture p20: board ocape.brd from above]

Board: 4 copper layers, 54.6 x 59.9 mm, 12 parts (0 on the bottom side), 12 nets.

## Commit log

2014-12-14 started on sensor board for swarmbox
    will sense movement, temp, light, etc
    [observer.brd, observer.sch]
2014-12-15 mostly routed
    [observer.brd, observer.sch]
2014-12-15 pretty close on the shield board
    [observer.brd, observer.sch, ocape.brd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]
2014-12-15 new design with mountable sensor board
    If the sensor board doesn't need to be attached elsewhere, it can be
    attached to the BBB cape.
    [observer.brd, observer.sch, ocape.brd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]
2014-12-16 working on sensor board
    [observer.brd, observer.sch, ocape.brd]
2014-12-16 basically done with observer
    [observer.brd, observer.sch, ocape.brd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]
2014-12-16 slight changes
    [observer.brd]
2014-12-17 shipped rev a
    [observer.brd, ocape.brd]
2014-12-17 docs for new boards
    [observer_bom.csv, observer_bom.xlsx, ocape_bom.csv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]
2015-01-18 Added files and information from Swarmbox workshop
    [swarmbox_BOM.xlsx]
2015-01-19 distilled bom for swarmbox
    [swarmbox_BOM.xlsx]

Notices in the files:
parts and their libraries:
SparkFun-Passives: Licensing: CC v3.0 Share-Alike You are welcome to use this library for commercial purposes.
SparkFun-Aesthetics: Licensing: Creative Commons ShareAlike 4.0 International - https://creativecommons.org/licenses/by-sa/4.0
